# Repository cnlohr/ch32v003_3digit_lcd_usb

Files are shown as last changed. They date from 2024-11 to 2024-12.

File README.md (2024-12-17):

# ch32v003_3digit_lcd_usb

USB, Touch and Driver for 3-digit 7-segment TN LCDs on CH32V003

[Youtube Video](https://www.youtube.com/watch?v=KNDRUWlsu0k)

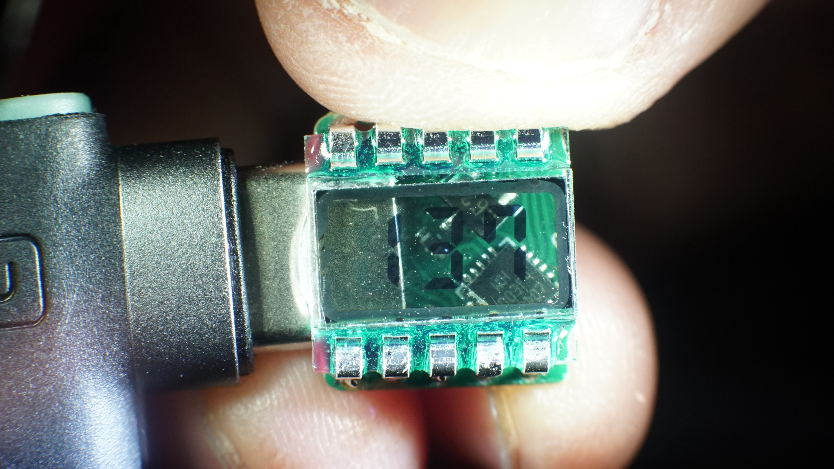
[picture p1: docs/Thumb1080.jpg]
glamour


Using a ch32v003, a 10 cent microcontroller, without USB, Touch or LCD Driving capaibilities to do all three at the same time.

## Design

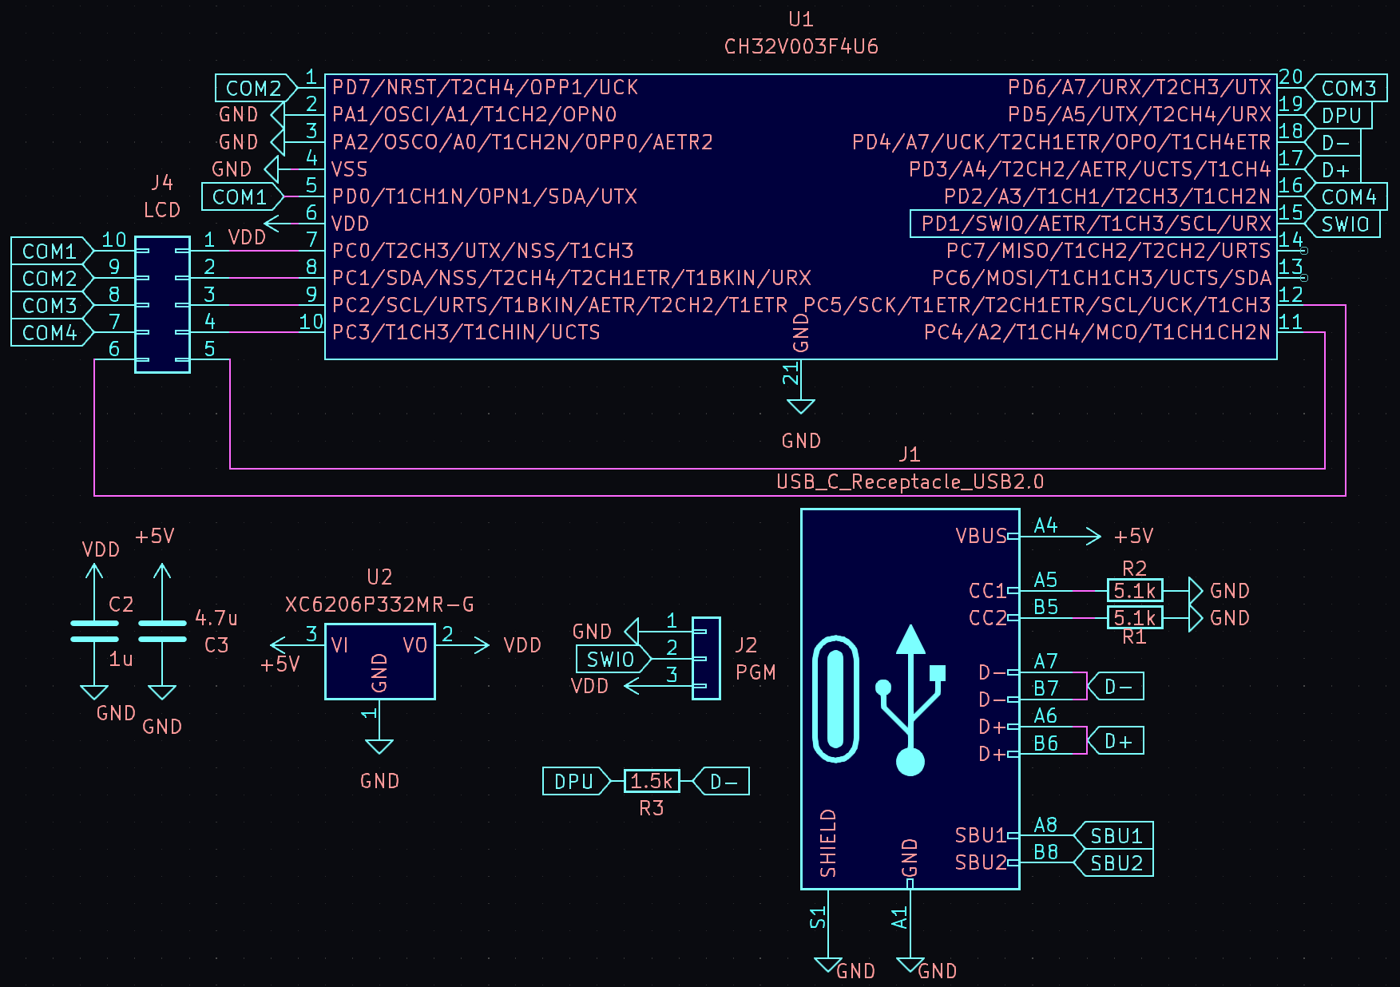
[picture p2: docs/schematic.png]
schematic


The design uses the reference rv003usb pinout, simply run the ch32v003 at 3.3v with an LDO and connect it up to the USB paddle card.

Conveniently the paddle card uses the same pinout as a normal USB Connector.

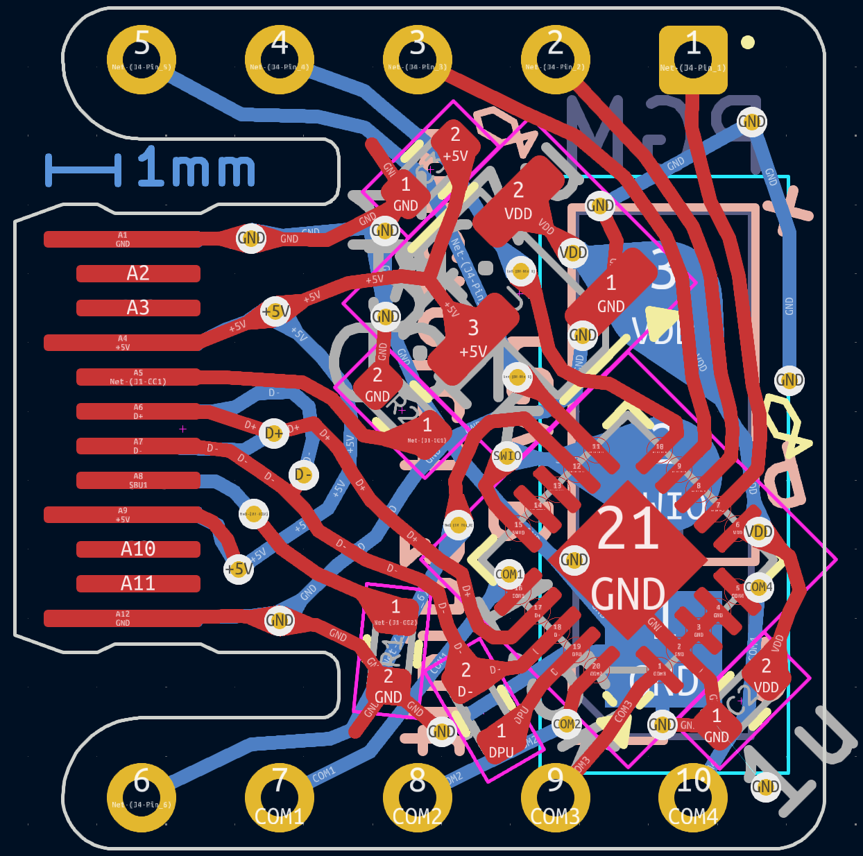
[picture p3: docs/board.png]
outline


The overall board uses the inside part of a USB Type C connector, but as part of the PCB, so there are the following two recommendations:

1. Your PCB should be 0.6mm thick.
2. Your PCB sohuld use ENIG finish instead of HASL, as it is possible a HASL finish could damage USB-C cables.

The ch32v003 needs no preprogramming, only access to the GND/SWIO/5V pins to flash the bootloader on.

To use this design, your LCD must be a 3V LCD and should match the following specification:

p1
p2

## Software

To flash on the software, you should:

 * Optionally, install the rv003usb bootloader.

Then, from either external programmer or bootloader,

 * In your desired firmware folder type `make option_write`
 * Flash with `make flash`

Appropriate firmware can be found in the firmware/ folders.  When cloning this repo, be sure to clone recursively, i.e.

```
git clone https://github.com/cnlohr/ch32v003_3digit_lcd_usb --recursive
```

or if you, forgot, cd into the folder and run:
```
git submodule update --init --recursive
```

## Touch Sensing

To perform touch sensing, we drive the line low, then, in concert with starting the ADC sample (and making sure the ADC setup/sample is aligned in time to Fcpu/2) we apply a pull-up resistor to all the ports on the LCD.

This causes a measurement to be made as the voltage on the pins common to the whole LCD is rising and this gives us our measurement.

## Waveforms

For basic LCD output, you can use a fairly simple waveform that has 10 stages.

 * Stages 0..3 = Specific COM pins are driven LOW in succession, while any segments to light are turned HIGH.
 * Stage 4 = Free time, make sure there is no voltage differential.  This also helps control contrast.
 * Stage 5..8 = Specific COM pins are driven HIGH in succession, while any segments to light are turned LOW.
 * Stage 9 = The other half of the free time for contrast.

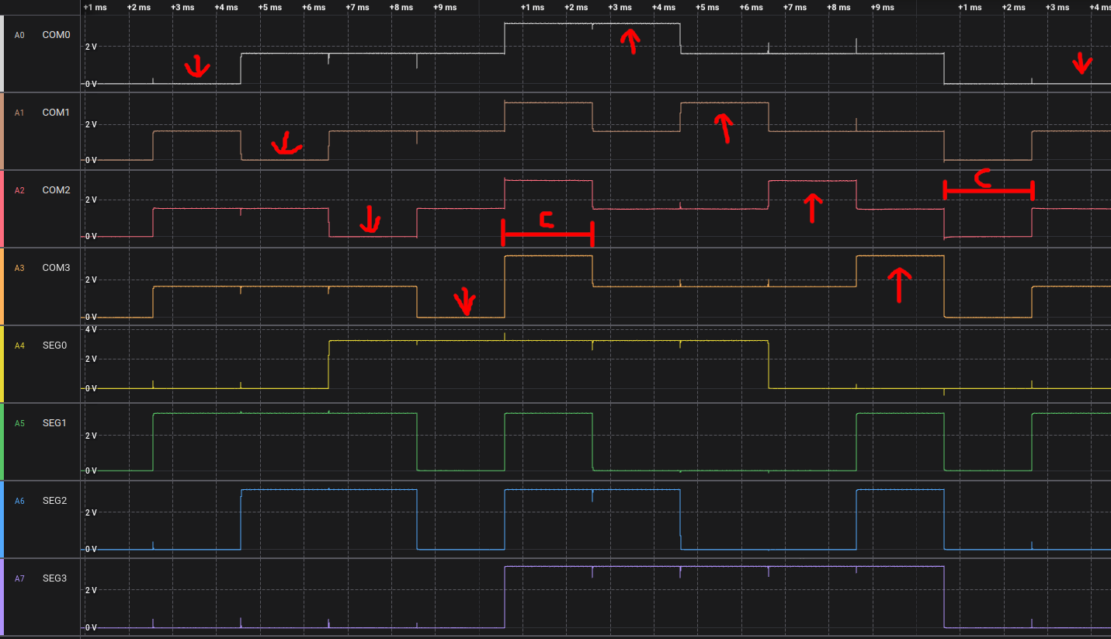
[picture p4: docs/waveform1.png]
waveform1


You can see how enabling USB wrecks things up, because with USB going, it can't regulate the SEG pins to 1/2 VCC.

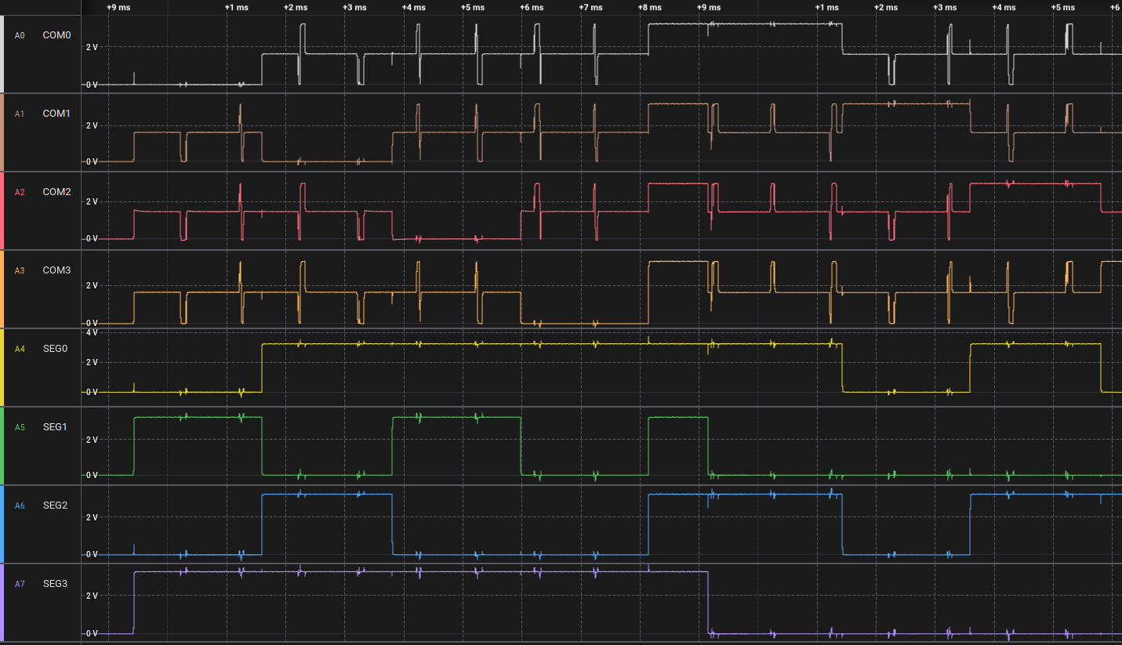
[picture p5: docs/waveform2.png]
waveform2


For touch, the output is repeatedly released from a low voltage with an internal pullup while simultaneously measuring the voltage with an ADC to obtain the touch amount.

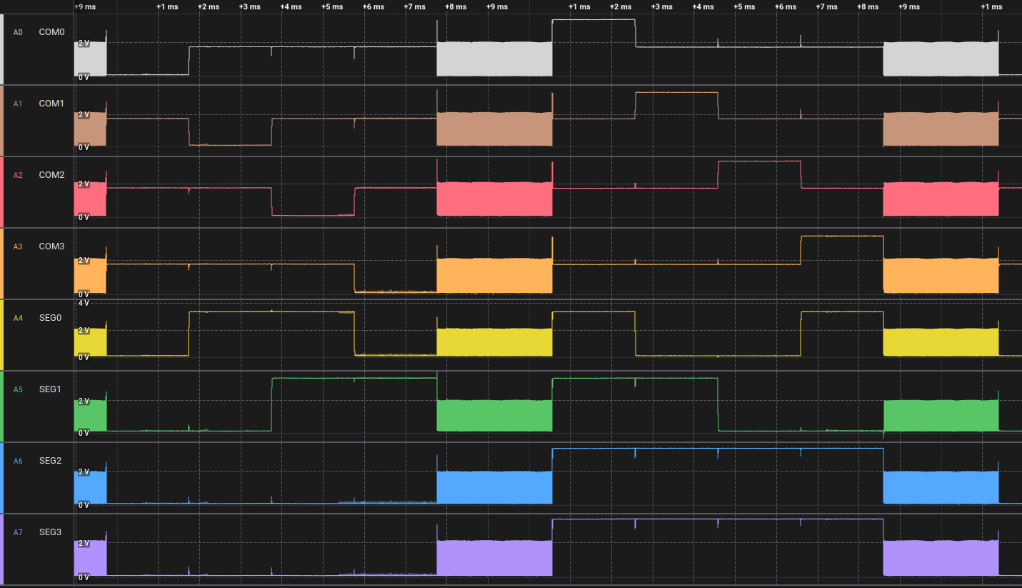
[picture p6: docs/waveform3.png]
waveform3


Which looks great until USB sails its boat into it.

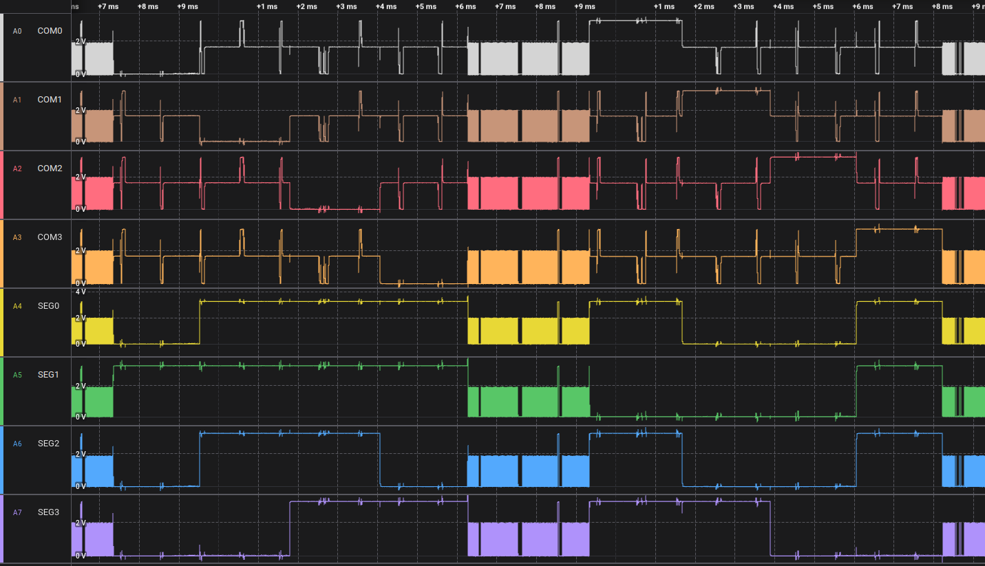
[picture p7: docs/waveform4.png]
waveform4


## Resources

 * Applicaiton Note: [NXP AN3129](https://www.nxp.com/docs/en/application-note/AN3219.pdf)
 * [ch32v003fun](https://github.com/cnlohr/ch32v003fun)
 * [rv003usb](https://github.com/cnlohr/ch32v003fun)

Search Aliexpress for "TN LCD Segment" to find these little bad boys.

## License

All code and designs may by licensed freely under the MIT/x11 License.

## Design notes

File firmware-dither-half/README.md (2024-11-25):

## Half-dither test

Unlike the super basic test, this uses "PWM" dithering.

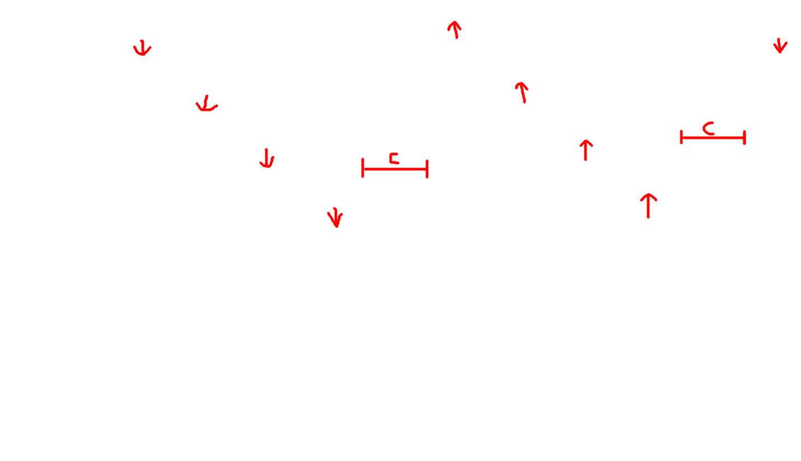
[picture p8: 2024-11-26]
docs/waveform1-overlay.png

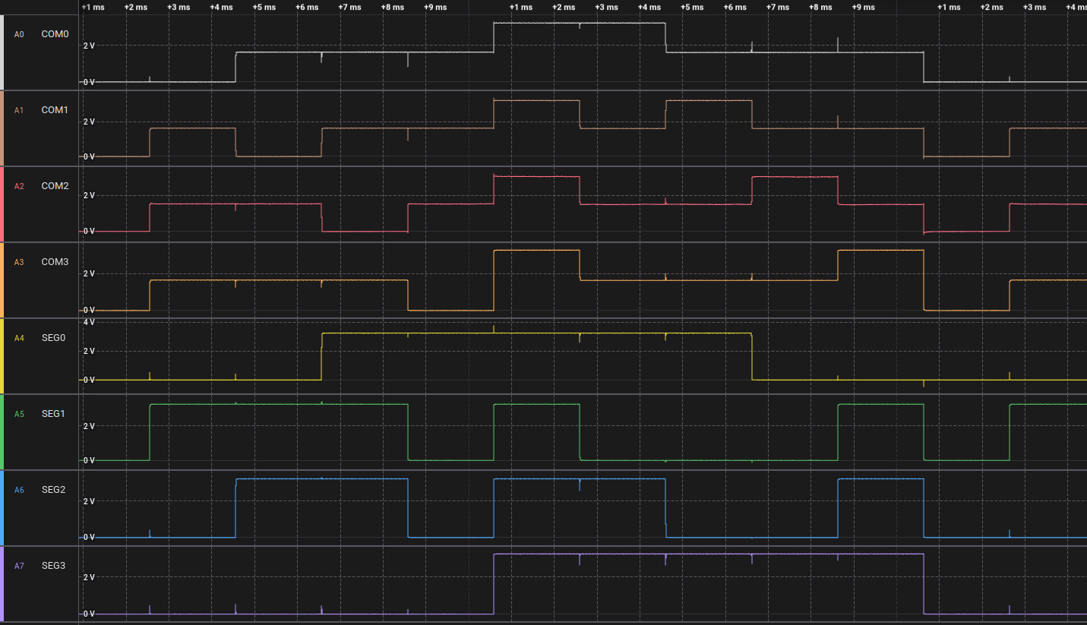
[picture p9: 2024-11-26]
docs/waveform0.png

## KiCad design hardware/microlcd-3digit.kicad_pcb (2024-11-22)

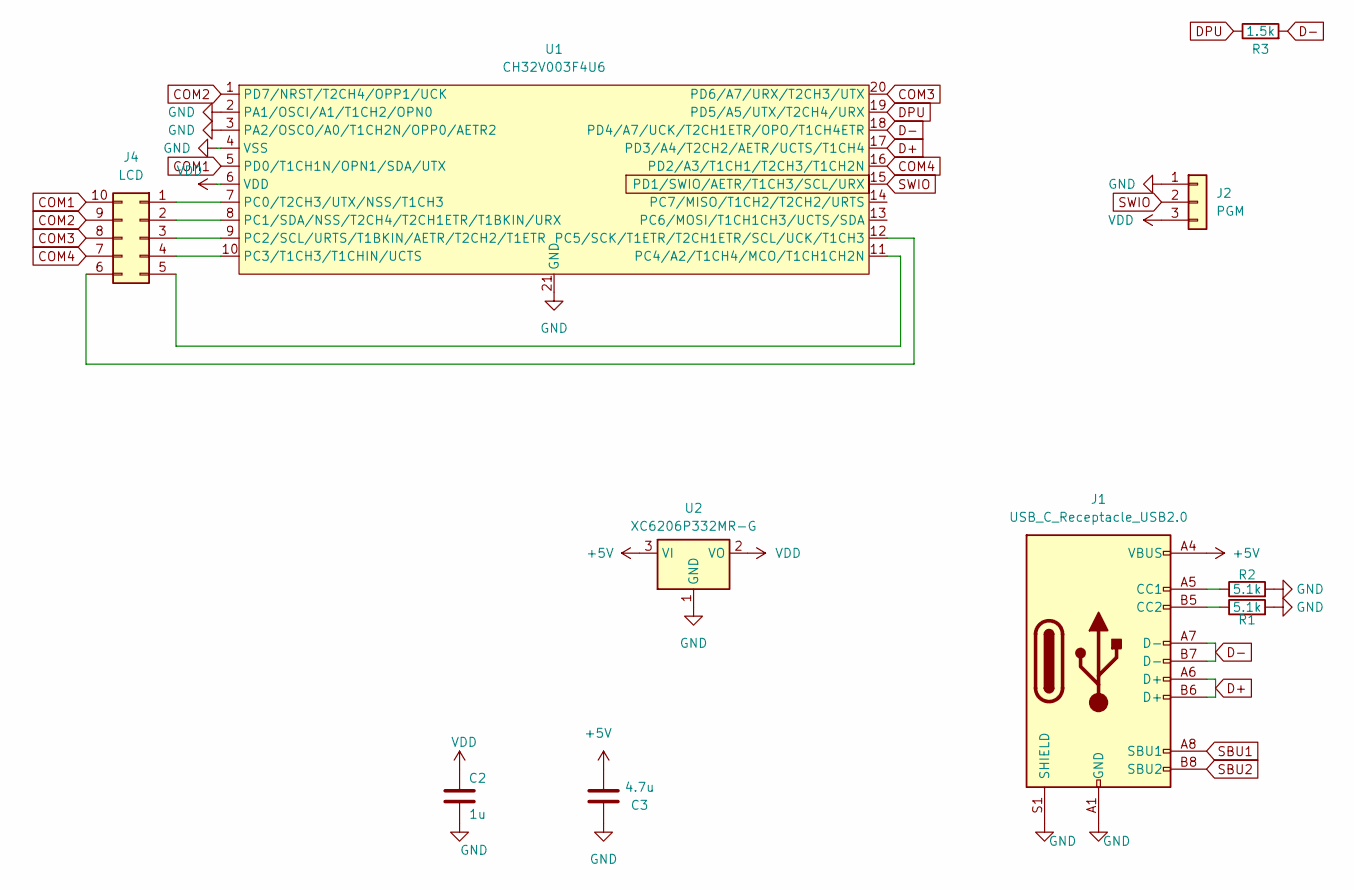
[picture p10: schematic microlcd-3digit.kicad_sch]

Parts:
C2: 1u; R_0402_1005Metric; LCSC C52923
C3: 4.7u; R_0402_1005Metric; LCSC C23733
J1: USB_C_Receptacle_USB2.0; USB_C_PADDLE
J2: PGM; PinHeader_1x03_P2.54mm_Vertical
J4: LCD; TINY_LCD_3_DIGIT
R1, R2: 5.1k; R_0402_1005Metric; LCSC C25905
R3: 1.5k; R_0402_1005Metric; LCSC C25867
U1: CH32V003F4U6; QFN-20-1EP_3x3mm_P0.4mm_EP1.65x1.65mm; LCSC C5299908
U2: XC6206P332MR-G; SOT-23; LCSC C5446

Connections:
+5V: C3.2, J1.A4 (VBUS), J1.A9 (VBUS), J1.B4 (VBUS), J1.B9 (VBUS), U2.3 (VI)
COM1: J4.7, U1.16 (PD2/A3/T1CH1/T2CH3/T1CH2N)
COM2: J4.8, U1.20 (PD6/A7/URX/T2CH3/UTX)
COM3: J4.9, U1.1 (PD7/NRST/T2CH4/OPP1/UCK)
COM4: J4.10, U1.5 (PD0/T1CH1N/OPN1/SDA/UTX)
D+: J1.A6 (D+), J1.B6 (D+), U1.17 (PD3/A4/T2CH2/AETR/UCTS/T1CH4)
D-: J1.A7 (D-), J1.B7 (D-), R3.2, U1.18 (PD4/A7/UCK/T2CH1ETR/OPO/T1CH4ETR)
DPU: R3.1, U1.19 (PD5/A5/UTX/T2CH4/URX)
GND: C2.1, C3.1, J1.A1 (GND), J1.A12 (GND), J1.B1 (GND), J1.B12 (GND), J1.S1 (SHIELD), J2.1, R1.2, R2.2, U1.2 (PA1/OSCI/A1/T1CH2/OPN0), U1.3 (PA2/OSCO/A0/T1CH2N/OPP0/AETR2), U1.4 (VSS), U1.21 (GND), U2.1 (GND)
unnamed: J1.A5 (CC1), R2.1
unnamed: J1.B5 (CC2), R1.1
unnamed: J4.1, U1.7 (PC0/T2CH3/UTX/NSS/T1CH3)
unnamed: J4.2, U1.8 (PC1/SDA/NSS/T2CH4/T2CH1ETR/T1BKIN/URX)
unnamed: J4.3, U1.9 (PC2/SCL/URTS/T1BKIN/AETR/T2CH2/T1ETR)
unnamed: J4.4, U1.10 (PC3/T1CH3/T1CHIN/UCTS)
unnamed: J4.5, U1.11 (PC4/A2/T1CH4/MCO/T1CH1CH2N)
unnamed: J4.6, U1.12 (PC5/SCK/T1ETR/T2CH1ETR/SCL/UCK/T1CH3)
SBU1: J1.A8 (SBU1)
SBU2: J1.B8 (SBU2)
SWIO: J2.2, U1.15 (PD1/SWIO/AETR/T1CH3/SCL/URX)
VDD: C2.2, J2.3, U1.6 (VDD), U2.2 (VO)

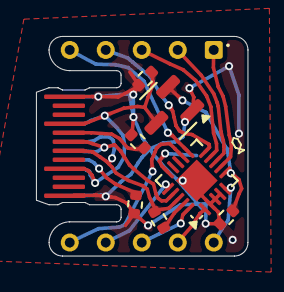
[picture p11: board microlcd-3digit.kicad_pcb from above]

Board: 2 copper layers, 11.8 x 12.2 mm, 10 parts (1 on the bottom side), 19 nets.

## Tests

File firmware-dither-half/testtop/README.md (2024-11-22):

# Based on hidapi demo for ch32v003

This just sends control messages down to the part that are formatted as a mask for what segments to light up on the LCD.

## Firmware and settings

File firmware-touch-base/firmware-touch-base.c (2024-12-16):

#include "ch32v003fun.h"
#include <stdio.h>
#include <string.h>
#include "rv003usb.h"

//#include "ch32v003_touch.h"

// Allow reading and writing to the scratchpad via HID control messages.
uint8_t scratch[63];
uint8_t scratchi[63];
volatile uint8_t start_out = 0;
volatile uint8_t start_in = 0;
uint8_t ledat;

#define LCDCOMBUF GPIOD

#define LCDCOM1 PD0
#define LCDCOM2 PD7
#define LCDCOM3 PD6
#define LCDCOM4 PD2
#define LCDCOMMASK1 (1<<0)
#define LCDCOMMASK2 (1<<7)
#define LCDCOMMASK3 (1<<6)
#define LCDCOMMASK4 (1<<2)
#define ALLCOMMASK (LCDCOMMASK1|LCDCOMMASK2|LCDCOMMASK3|LCDCOMMASK4)

#define LCDSEGBUF GPIOC

#define LCDSEG0 PC0
#define LCDSEG1 PC1
#define LCDSEG2 PC2
#define LCDSEG3 PC3
#define LCDSEG4 PC4
#define LCDSEG5 PC5
#define ALLSEGMASK (0x3f)
static const uint8_t pinset[4] = { LCDCOM1, LCDCOM2, LCDCOM3, LCDCOM4 };


// from host
static uint32_t lastmask;
static uint32_t touchval;

// LCD Is 10PIN TN Positive 3-Digits 7 Segment LCD Panel 3.0V

//  bbb
//  a d
//  ccc
//  e f
//  ggg
// ab0000cd0000ef0000g0

const uint32_t digits[16] = {
	0b11000001000011000010, // 0
	0b00000001000001000000, // 1
	0b01000011000010000010, // 2
	0b01000011000001000010, // 3
	0b10000011000001000000, // 4
	0b11000010000001000010, // 5
	0b11000010000011000010, // 6
	0b11000001000001000000, // 7
	0b11000011000011000010, // 8
	0b11000011000001000010, // 9
	0b11000011000011000000, // A
	0b10000010000011000010, // b
	0b00000010000010000010, // c
	0b00000011000011000010, // d
	0b11000010000010000010, // e
	0b11000010000010000000, // f
};

uint32_t ComputeLCDMaskWithNumber( uint32_t val )
{
	int i;
	uint32_t mask = 0;
	for( i = 0; i < 3; i++ )
	{
		uint32_t vv = (val >> 8);
		mask <<= 2;
		if( vv > 0 || i == 2 )
		{
			mask |= digits[vv & 0xf];
		}
		val <<= 4;
	}
	return mask;
}

void RunTouch()
{
	// Touch runs for about 1ms.
	// Configure touch!
	// Touch pin = 3 or 6 
	// I tried seeing if you could get data by measuring one or the other, and the answer was basically no.
	// I couldn't get any extra data.
	int reads = 0;
	int group;
	const int oversample = 300; // Has significant impact over contrast.

#define FORCEALIGNADC \
	asm volatile( \
		"\n\
		.balign 4\n\
		andi a2, %[cyccnt], 3\n\
		c.slli a2, 1\n\
		c.addi a2, 12\n\
		auipc a1, 0\n\
		c.add  a2, a1\n\
		jalr a2, 1\n\
		.long 0x00010001\n\
		.long 0x00010001\n\
		"\
		:: [cyccnt]"r"(SysTick->CNT) : "a1", "a2"\
	);

	int ttv = 0;

	const int adcno = 3;
	#define SPECIAL_TOUCH_ADC_SAMPLE_TIME 1

	__disable_irq();
	FORCEALIGNADC
	ADC1->RSQR3 = adcno;
	ADC1->SAMPTR2 = SPECIAL_TOUCH_ADC_SAMPLE_TIME<<(3*adcno);
	__enable_irq();

	Delay_Us(1);
	for( reads = 0; reads < oversample; reads++ )
	{

#if LOCKIN_AMP_MODE
		// Lock-in amplifier mode only useful for when we can control timing of inner loop
		// I.e. if using DMA to do touch reads.  Don't do this 

		__disable_irq();
		FORCEALIGNADC
		ADC1->CTLR2 = ADC_SWSTART | ADC_ADON | ADC_EXTSEL;
		LCDSEGBUF->BSHR = 0x3f<<16;
		LCDCOMBUF->BSHR = ALLCOMMASK<<16;
		__enable_irq();
		while(!(ADC1->STATR & ADC_EOC));
		int tvu = ADC1->RDATAR;
#else
		// Non-lock-in mode (You should use this)
		LCDSEGBUF->BSHR = 0x3f<<16;
		LCDCOMBUF->BSHR = ALLCOMMASK<<16;
		for( group = 0; group < 4; group++ )
			funPinMode( pinset[group], GPIO_CFGLR_OUT_2Mhz_PP );
		funPinMode( LCDSEG0, GPIO_CFGLR_OUT_2Mhz_PP );
		funPinMode( LCDSEG1, GPIO_CFGLR_OUT_2Mhz_PP );
		funPinMode( LCDSEG2, GPIO_CFGLR_OUT_2Mhz_PP );
		funPinMode( LCDSEG3, GPIO_CFGLR_OUT_2Mhz_PP );
		funPinMode( LCDSEG4, GPIO_CFGLR_OUT_2Mhz_PP );
		funPinMode( LCDSEG5, GPIO_CFGLR_OUT_2Mhz_PP );

		for( group = 0; group < 4; group++ )
			funPinMode( pinset[group], GPIO_CFGLR_IN_PUPD );
		funPinMode( LCDSEG0, GPIO_CFGLR_IN_PUPD );
		funPinMode( LCDSEG1, GPIO_CFGLR_IN_PUPD );
		funPinMode( LCDSEG2, GPIO_CFGLR_IN_PUPD );
		funPinMode( LCDSEG3, GPIO_CFGLR_IN_PUPD );
		funPinMode( LCDSEG4, GPIO_CFGLR_IN_PUPD );
		funPinMode( LCDSEG5, GPIO_CFGLR_IN_PUPD );
#endif

		__disable_irq();
		FORCEALIGNADC
		ADC1->CTLR2 = ADC_SWSTART | ADC_ADON | ADC_EXTSEL;
		LCDSEGBUF->BSHR = 0x3f;
		LCDCOMBUF->BSHR = ALLCOMMASK;
		__enable_irq();
		while(!(ADC1->STATR & ADC_EOC));
		int tvd = ADC1->RDATAR;
#if LOCKIN_AMP_MODE
		ttv += tvu - tvd;
#else
		ttv += tvd;
#endif
	}
	touchval += ttv;
}

// Background for below code:
// The bottom 16 bits of BSHRC says to set these IO pins high.
// The top 16 bits of BSHRC says to turn off the corresponding IO pins.

void DitherIO( volatile uint32_t * bshr, uint32_t da, uint32_t db, int iterations ) __attribute__((noinline));
void DitherIO( volatile uint32_t * bshr, uint32_t da, uint32_t db, int iterations )
{
	// This is not written this way because it needs to be fast, but that I want to make sure
	// that it takes as many cycles on the high-side as it does on the low-side when dithering.
	// Loops are realy slow on the 003, and no reason not to make it bigger.
	//
	if( iterations == 0 ) return;

	asm volatile(
		".balign 4\n"
		"1:\n"
		"	c.sw %[db], 0(%[bshr])\n"
		"	c.nop\n"
		"	c.nop\n"
		"	c.addi %[iterations], -1\n"
		"	c.beqz %[iterations], 2f\n"
		"	c.sw %[da], 0(%[bshr])\n"
		"	c.j 1b\n"
		"2:"
		: [iterations]"+r"(iterations)
		: [bshr]"r"(bshr),
		  [da]"r"(da),
		  [db]"r"(db)
		:  );	
}

void UpdateLCD( uint32_t mask )
{
	int group;
	const int dithers = 8000;

	#define drivepr GPIO_CFGLR_IN_PUPD
	for( group = 0; group < 4; group++ )
		funPinMode( pinset[group], drivepr );
	funPinMode( LCDSEG0, drivepr );
	funPinMode( LCDSEG1, drivepr );
	funPinMode( LCDSEG2, drivepr );
	funPinMode( LCDSEG3, drivepr );
	funPinMode( LCDSEG4, drivepr );
	funPinMode( LCDSEG5, drivepr );

	static const uint8_t commasks[4] = { LCDCOMMASK1, LCDCOMMASK2, LCDCOMMASK3, LCDCOMMASK4 };

	int tm = ~mask;
	// Reset SEG mask for this run.
	LCDSEGBUF->BSHR = ALLSEGMASK<<16;
	for( group = 0; group < 4; group++ )
	{
		int commasknthis = commasks[group] ^ ALLCOMMASK;

		LCDSEGBUF->BSHR = tm&ALLSEGMASK;
		DitherIO( &LCDCOMBUF->BSHR, (commasknthis<<16), ALLCOMMASK, dithers );
		LCDSEGBUF->BSHR = ALLSEGMASK<<16;
		tm>>=6;
	}

	// Turn off all SEGs (all COMs are off here too)
	LCDCOMBUF->BSHR = ALLCOMMASK<<16;

	// Delay some time - this is the "clear" time.
	// This should be balanced with the bottom (Theoretically)
	RunTouch();

	// Now, we invert our mask (what segments we are trying to command on/off)
	tm = ~mask;

	// Set seg mask for this run.
	LCDSEGBUF->BSHR = ALLSEGMASK;
	for( group = 0; group < 4; group++ )
	{
		int commasknthis = (commasks[group] ^ ALLCOMMASK);

		LCDSEGBUF->BSHR = tm<<16;
		DitherIO( &LCDCOMBUF->BSHR, commasknthis, ALLCOMMASK<<16, dithers );
		LCDSEGBUF->BSHR = ALLSEGMASK;
		tm>>=6;
	}
	// Turn on SEGs off (All COMs are on here too)
	LCDCOMBUF->BSHR = ALLCOMMASK;

	RunTouch();

	// Not sure why this is needed?
	Delay_Us(1); 
}

int main()
{
	SystemInit();
	Delay_Ms(3); // Ensures USB re-enumeration after bootloader or reset; Spec demand >2.5µs ( TDDIS )
	usb_setup();

	funGpioInitAll();
	RCC->APB2PCENR |= RCC_APB2Periph_ADC1;

	int id = 0;
	int didaffect = 0;

	int calstage = 20;
	int cal = 0;
	int press = 0;
	int touchstate = 0;
	int touchsum = 0;

	int dv = 0;
	while(1)
	{
		id++;
		if( !didaffect )
		{
			UpdateLCD( ComputeLCDMaskWithNumber( dv ) );
		}
		else
		{
			UpdateLCD( lastmask );
		}

		touchsum += touchval;
		touchval = 0;

		if( ++touchstate >= 1 )
		{
			//printf( "%d\n", touchsum );
			if( calstage > 0 )
			{
				calstage--;
				if( calstage < 16 ) cal += touchsum;
			}
			else
			{
				int event = 0;
				int rezero = (cal>>4) - touchsum;
				if( rezero > 100 ) cal-=1000;
				if( rezero < -100 ) cal+=10000;
				if( rezero > 4000 && press == 0 ) { press = 1; event = 1; }
				if( rezero < 2000 && press == 1) { press = 0; event = 1; }
				if( event && press )
					dv++;
			}
			memcpy( scratchi + 1, &touchsum, 4 );
			scratchi[0] = 0xaa;
			scratchi[5] = dv;
			touchsum = touchstate = 0;
		}

#if RV003USB_EVENT_DEBUGGING
		uint32_t * ue = GetUEvent();
		if( ue )
		{
			printf( "%lu %lx %lx %lx\n", ue[0], ue[1], ue[2], ue[3] );
		}
#endif
		if( start_out )
		{
			memcpy( &lastmask, scratch+1, 4 );
			didaffect = 1;
			start_out = 0;
		}
	}
}

void usb_handle_user_in_request( struct usb_endpoint * e, uint8_t * scratchpad, int endp, uint32_t sendtok, struct rv003usb_internal * ist )
{
	// Make sure we only deal with control messages.  Like get/set feature reports.
	if( endp )
	{
		usb_send_empty( sendtok );
	}
}

void usb_handle_user_data( struct usb_endpoint * e, int current_endpoint, uint8_t * data, int len, struct rv003usb_internal * ist )
{
	//LogUEvent( SysTick->CNT, current_endpoint, e->count, 0xaaaaaaaa );
	int offset = e->count<<3;
	int torx = e->max_len - offset;
	if( torx > len ) torx = len;
	if( torx > 0 )
	{
		memcpy( scratch + offset, data, torx );
		e->count++;
		if( ( e->count << 3 ) >= e->max_len )
		{
			start_out = e->max_len;
		}
	}
}

void usb_handle_hid_get_report_start( struct usb_endpoint * e, int reqLen, uint32_t lValueLSBIndexMSB )
{
	if( reqLen > sizeof( scratchi ) ) reqLen = sizeof( scratchi );

	// You can check the lValueLSBIndexMSB word to decide what you want to do here
	// But, whatever you point this at will be returned back to the host PC where
	// it calls hid_get_feature_report. 
	//
	// Please note, that on some systems, for this to work, your return length must
	// match the length defined in HID_REPORT_COUNT, in your HID report, in usb_config.h

	e->opaque = scratchi;
	e->max_len = reqLen;
}

void usb_handle_hid_set_report_start( struct usb_endpoint * e, int reqLen, uint32_t lValueLSBIndexMSB )
{
	// Here is where you get an alert when the host PC calls hid_send_feature_report.
	//
	// You can handle the appropriate message here.  Please note that in this
	// example, the data is chunked into groups-of-8-bytes.
	//
	// Note that you may need to make this match HID_REPORT_COUNT, in your HID
	// report, in usb_config.h

	if( reqLen > sizeof( scratch ) ) reqLen = sizeof( scratch );
	e->max_len = reqLen;
}


void usb_handle_other_control_message( struct usb_endpoint * e, struct usb_urb * s, struct rv003usb_internal * ist )
{
	LogUEvent( SysTick->CNT, s->wRequestTypeLSBRequestMSB, s->lValueLSBIndexMSB, s->wLength );
}

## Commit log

2024-11-25 Swap things around to use dither control for generating 1/2 VCC
    [demo_microlcd-3digit.c, firmware-dither-half.c]
2024-11-26 Fixup touch code to be perfect.
    [firmware-touch-base.c]
2024-12-04 Add keyboard-only-f-button
2024-12-16 Update content
    [microlcd-3digit.kicad_sch]
